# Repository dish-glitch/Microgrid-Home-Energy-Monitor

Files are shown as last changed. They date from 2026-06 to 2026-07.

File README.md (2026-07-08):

# Home Energy Monitor

**A custom PCB that measures real-time household power consumption (Watts, apparent power (VA), and power factor) and streams live data to an OLED screen, a WiFi dashboard, and a Modbus TCP/IP server (the same protocol real industrial power meters use).**







---

## Schematic Preview



---

## PCB Preview



## Enclosure Preview

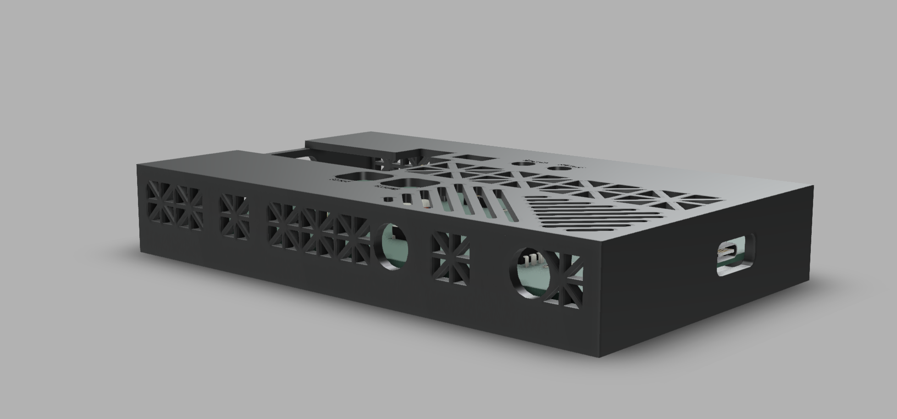
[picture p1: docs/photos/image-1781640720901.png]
Enclosure render

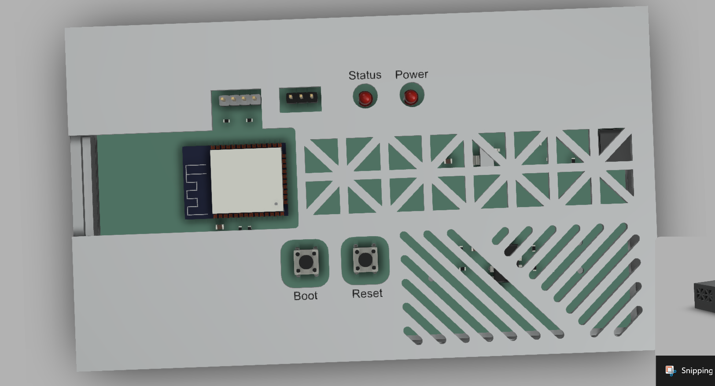
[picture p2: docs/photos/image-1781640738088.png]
Enclosure top view


---

## What It Does

Non-invasive current transformer (CT) sensors clip around household wires inside a breaker box(does not touch any live wires). The custom PCB conditions the signal from the sensors and feeds it to an ESP32 microcontroller. The microcontroller then samples the voltage and current to compute:

- **Real Power (Watts)** 
- **Apparent Power (VA)**
- **Power Factor** 
- **Cumulative kWh** 

The readings come out three ways: a small OLED on the device, a live dashboard served over WiFi that you can open in any browser, and a Modbus TCP/IP server so industrial software like PLCs, SCADA, or Home Assistant can read the meter directly.

---

## How It Works

The SCT-013 current clamp outputs a small AC signal that mirrors the current in the wire it's clamped around. Before the ESP-32 is able to sample the signal, it must condition it. 

1. **It swings negative** — the ESP32 ADC only reads 0–3.3V. An op-amp bias circuit lifts the signal to a 1.65V midpoint so it never goes below 0V.
2. **It's in the wrong units** — a burden resistor converts current to a readable voltage via Ohm's Law (V = I × R).
3. **It carries noise** — an RC low-pass filter passes 60Hz but blocks high-frequency interference.

The ESP32 samples the signal and calculates RMS values in firmware and then uses those measurements to produce real power, apparent power, and power factor. 

---

## Modbus TCP/IP

I added a Modbus TCP server so this works more like a real industrial power meter instead of just a hobby project. Modbus is the protocol that commercial meters from companies like Schneider Electric and ABB use to send their readings to building systems and SCADA software. I got the idea from a PLC Dojo certification I finished on programming Modbus TCP clients and servers, and I wanted to actually use what I learned on my own hardware.

The ESP32 runs the Modbus server on port 502 at the same time as the web dashboard on port 80, so both run off the same WiFi. Any Modbus client, like a PLC, SCADA software, Home Assistant, Node-RED, or even a Python script, can read the meter by asking for its holding registers with Function Code 3.

Modbus registers can only hold 16-bit whole numbers, so I scale the decimal readings into whole numbers before writing them, and the client divides by the same number to get the real value back.

| Register | Modbus Address | Value | Scaling | Example |
|---|---|---|---|---|
| 0 | 40001 | Voltage (Vrms) | ×10 | `1200` → 120.0 V |
| 1 | 40002 | Current CH1 (Irms) | ×100 | `500` → 5.00 A |
| 2 | 40003 | Real Power CH1 (W) | ×1 | `600` → 600 W |
| 3 | 40004 | Apparent Power CH1 (VA) | ×1 | `650` → 650 VA |
| 4 | 40005 | Power Factor | ×100 | `92` → 0.92 |
| 5 | 40006 | Total Energy (kWh) | ×10 | `123` → 12.3 kWh |
| 6 | 40007 | Current CH2 (Irms) | ×100 | `300` → 3.00 A |
| 7 | 40008 | Real Power CH2 (W) | ×1 | `360` → 360 W |

> Register 0 in the code shows up as 40001 in most Modbus software. The 4xxxx numbering is just the standard way holding registers get labeled.

---

## Hardware

> Prices are what you actually pay per order, not per component. Amazon prices fluctuate — check links for current pricing. Order DigiKey items together to share one shipping fee (~$8 flat).

| Component | Ref | Need | What to Buy | Pack | Est. Order Price | Where |
|---|---|---|---|---|---|---|
| ESP32-WROOM-32 module | U1 | 1 | ESP-WROOM-32D 5-pack | 5 | ~$16 | [Amazon][(https://www.amazon.com/ESP-WROOM-32D-ESP-32-Bluetooth-Module-ESP32-WROOM-32D/dp/B085BNHPW5)](https://www.amazon.com/DORHEA-ESP-WROOM-32D-Bluetooth-integrates-ESP32-D0WD/dp/B08XXH9RMT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) |
| CT sensor SCT-013-000 (100A) | J1, J2 sensors | 2 | KOOBOOK 2-pack | 2 | ~$15 | [Amazon](https://www.amazon.com/KOOBOOK-SCT-013-000-Non-invasive-Current-Transformer/dp/B07S4G2Y27) |
| ZMPT101B voltage sensor module | J6 sensor | 1 | Single module | 1 | ~$8 | Amazon |
| Op-amp MCP6002 DIP-8 | U2 | 1 | Juried Engineering 1-pack | 1 | ~$4 | [Amazon](https://www.amazon.com/MICROCHIP-MCP6002-I-MCP6002-Operational-Amplifier/dp/B07GMWJ523) |
| Voltage regulator AMS1117-3.3 | U3 | 1 | 10-pack SOT-223 | 10 | ~$6 | [Amazon](https://www.amazon.com/AMS1117-3-3-LM1117-SOT-223-Voltage-Regulator/dp/B00Y5EKAU2) |
| SMD resistors 0603 (33Ω, 10kΩ, 4.7kΩ, 5.1kΩ, 150Ω) | R1–R14 | 14 total | 0603 assortment kit — covers all 5 values | 660pc / 33 values | ~$9 | [Amazon](https://www.amazon.com/660pcs-0603-Resistors-Assortment-Values/dp/B0CH2XD7JY) |
| SMD capacitors 0603+0805 (100nF, 10µF) | C1–C9 | 9 total | 0603/0805 assortment kit (10pF–22µF) | 960pc / 16 values | ~$10 | [Amazon](https://www.amazon.com/Capacitor-10pF-22uF-Multilayer-Capacitors-Assortment/dp/B094Z9V5KK) |
| 3.5mm audio jack SMT (CUI SJ-3523-SMT) | J1, J2 | 2 | Order 2 individually | 2 | ~$5 | [DigiKey](https://www.digikey.com/en/products/detail/same-sky-formerly-cui-devices/SJ-3523-SMT-TR/281297) |
| USB-C receptacle (GCT USB4085-GF-A) | J4 | 1 | Order 1 individually | 1 | ~$1 | [DigiKey](https://www.digikey.com/en/products/detail/gct/USB4085-GF-A/9859662) |
| 3mm LED (red or green) | D1, D2 | 2 | 10-pack | 10 | ~$5 | [Amazon](https://www.amazon.com/3mm-Round-Top-Red-LED/dp/B017TR4XWW) |
| Tactile button 6×6×4.3mm THT | SW1, SW2 | 2 | 10-pack | 10 | ~$5 | [Amazon](https://www.amazon.com/6x6x4-3mm-Momentary-Tactile-Button-Through/dp/B00EDJYK46) |
| 2.54mm male pin headers (J3 4-pin, J5 6-pin, J6 3-pin) | J3, J5, J6 | 13 pins | 40-pin breakable strip (snap to length) | 10×40 strips | ~$6 | [Amazon](https://www.amazon.com/MCIGICM-Header-2-45mm-Arduino-Connector/dp/B07PKKY8BX) |
| SSD1306 OLED 0.96" I2C | J3 display | 1 | Single unit | 1 | ~$7 | [Amazon](https://www.amazon.com/SSD1306-Display-128x64-Driver-Screen/dp/B0GRGLP6WW) |
| CP2102 USB-to-UART programmer (to flash via J5) | — | 1 | HiLetgo CP2102 | 1 | ~$7 | [Amazon](https://www.amazon.com/HiLetgo-CP2102-Converter-Adapter-Downloader/dp/B00LODGRV8) |
| PCB fabrication | — | 1 run | JLCPCB 5 boards + shipping | 5 boards | ~$20 | [JLCPCB](https://jlcpcb.com) |
| Enclosure | — | 1 | 3D printed PETG-CF | — | $0 | filament on hand |
| DigiKey shipping | — | — | Flat rate (order SJ-3523 + USB4085 together) | — | ~$8 | — |
| **Total** | | | | | **~$132** | |

---

## Repository Structure

```
home-energy-monitor/
├── hardware/        # KiCad schematic, PCB layout, Gerber files
├── firmware/        # ESP32 Arduino code
├── enclosure/       # FreeCAD source + STL files for 3D printing
└── docs/
    └── photos/      # Build progress photos
```

---

## Build Log

| Date | Milestone |
|---|---|
| June 10, 2026 | Project started. Repository initialized. |
| June 11, 2026 | KiCad schematic started — analog front-end both CT channels complete |
| June 13, 2026 | KiCad schematic complete — ERC passes clean, all components wired |
| June 14, 2026 | PCB layout complete — all components placed, routed, ground plane poured, DRC clean |
| June 14, 2026 | Gerbers exported and committed — ready for JLCPCB upload |
| June 14, 2026 | Firmware written — RMS sampling, power math, OLED display, kWh accumulator. Verified on Wokwi simulator. |
| June 15, 2026 | WiFi dashboard complete — ESP32 serves live readings over HTTP, JavaScript polls every second |
| June 16, 2026 | 3D enclosure designed by [@hummos430](https://github.com/hummos430) in Fusion 360 — files committed |
| June 16, 2026 | Stardance funding submitted — S tier $150 |
| July 3, 2026 | DRC audit fixes — solid B.Cu ground plane added, ESP32 thermal via drills fixed, USB-C clearance rule corrected. ERC + DRC verified 0 errors. Gerbers re-exported — board ready to order |
| July 8, 2026 | Modbus TCP/IP server added — ESP32 exposes 8 holding registers on port 502, runs alongside the web dashboard |
| — | PCBs ordered from JLCPCB |
| — | PCBs arrived, soldering complete |
| — | Firmware calibrated, first real power readings |
| — | Dashboard live, full system working |

---

## Simulation

Test the firmware logic without hardware — runs in browser:



Simulates dual CT sensor readings, RMS power math, serial output, and OLED display on a virtual ESP32. CH1 uses test values (120V, 5A, 550W, PF 0.92) to verify the signal chain and kWh accumulator logic.

---

## Status

- [x] KiCad schematic — ERC clean (0 errors)
- [x] PCB layout — DRC clean (0 violations, 0 unconnected); B.Cu ground plane added
- [x] Gerbers exported from the DRC-clean board — ready for JLCPCB upload
- [x] Firmware — ADC sampling + RMS math
- [x] Firmware — power factor calculation
- [ ] PCB fabrication (JLCPCB)
- [x] 3D enclosure design
- [x] WiFi dashboard
- [x] Modbus TCP/IP server (8 holding registers, Function Code 3)
- [ ] Full system test

---

## Acknowledgements

- **[@hummos430](https://github.com/hummos430)** — Designed and 3D printed the enclosure in Fusion 360
- **[Claude (Anthropic)](https://claude.ai)** — Claude was used to help document this project. I often recorded voice notes describing my engineering ideas, design decisions, and progress, then used Claude to organize those notes into structured GitHub documentation and tables. It also helped review the BOM and sanity-check component selections for consistency. The schematic, PCB layout, firmware, testing, and engineering decisions are my own.

---

## License

MIT — use, modify, share freely. See [LICENSE](LICENSE).

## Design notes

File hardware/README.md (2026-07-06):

# Hardware

Custom 2-layer PCB designed in KiCad 9. Measures real-time household power consumption using non-invasive current transformer sensors.

---

## PCB Specifications

| Spec | Value |
|---|---|
| Layers | 2 (F.Cu / B.Cu) |
| Board dimensions | ~130mm × 75mm |
| Min trace width | 0.2mm signal / 0.4mm power |
| Min clearance | 0.15mm (accommodates the USB-C footprint's pad spacing; JLCPCB handles down to 0.127mm) |
| Copper pour | GND flood on F.Cu + solid GND plane on B.Cu, joined by stitching vias |
| Via drill | 0.3mm min |
| Surface finish | HASL (lead-free) |
| Fabrication | JLCPCB |

---

## Design Overview

### Power Path
USB-C (5V VBUS) → AMS1117-3.3 linear regulator → 3.3V rail → ESP32 + all peripherals

CC1 and CC2 resistors (5.1kΩ to GND) identify the board as a USB device to the host charger, enabling 5V/500mA delivery per USB-C spec.

### CT Sensor Signal Conditioning (per channel)
Each channel processes the AC output of an SCT-013-000 current transformer:

```
SCT-013 → 33Ω burden resistor → 10µF coupling cap → MCP6002 op-amp buffer → ESP32 ADC
                                    ↑
                          10kΩ/10kΩ bias divider (1.65V midpoint)
```

1. **Burden resistor (33Ω):** The SCT-013 outputs a small currecnt but the ESP32 measures the voltage. The 33 ohm burden resisotr converts that currecnt into a voltage using Ohm's law. At the senors's max rated current, this produeces 1.65 V RMS 2.33 V peak. 

2. **Bias divider (2× 10kΩ):** Becuase the ESP32 ADC can't read negative voltages, 2 10k ohm resistors create a 1.65 V bais point.
3. **Coupling capacitor (10µF):** Blocks DC from the burden resistor, and passes the 60Hz AC signal.
4. **MCP6002 buffer:** Unity-gain op-amp buffer to keep the bais network independent from the ESP32 ADC. Its high imput impedance prevents the bais voltage from shifting. 

### Voltage Sensing
ZMPT101B voltage transformer connects to J6. its output is routed to GPIO36 which is an input-only ADC pin with no internal pull resistors, chosen to minimize noise on the analog signal.

### I2C Bus
SDA (GPIO21) and SCL (GPIO22) pulled up to 3.3V via 4.7kΩ resistors. Pull-up value chosen for standard-mode I2C (100 kHz) with expected bus capacitance under 50pF.

### ESP32 Boot Circuit
- EN pulled high via 10kΩ (R7) + 100nF to GND for clean power-on reset
- GPIO0 pulled high via 10kΩ (R10); SW2 pulls GPIO0 low for bootloader entry
- SW1 pulls EN low for hard reset

---

## Schematic

See [`Microgrid-Home-Energy-Monitor.kicad_sch`](Microgrid-Home-Energy-Monitor.kicad_sch)

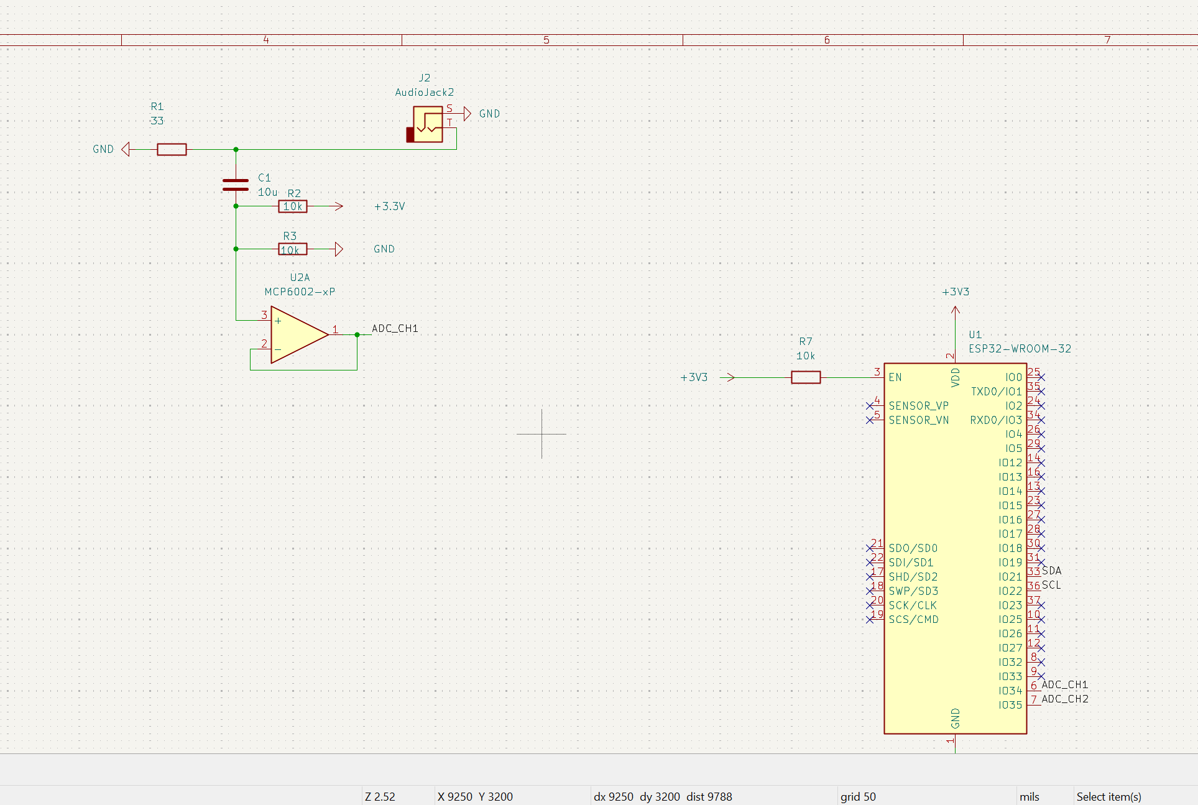
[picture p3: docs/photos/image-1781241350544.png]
Schematic


---

## PCB Layout

See [`Microgrid-Home-Energy-Monitor.kicad_pcb`](Microgrid-Home-Energy-Monitor.kicad_pcb)

Key layout decisions:
- Analog front-end (J1, J2, U2, bias resistors) grouped bottom-right, away from ESP32 WiFi antenna
- ESP32 antenna overhangs the keepout zone — no copper pour under antenna area
- AMS1117 decoupling caps (C3–C6) placed within 2mm of regulator pins
- ESP32 VDD decoupling (C7, C8) placed directly below VDD pin
- USB-C connector (J4) edge-mounted on right wall for direct cable access
- Ground pour floods entire F.Cu layer

---

## Bill of Materials

| Ref | Component | Value | Package | MPN | Supplier |
|---|---|---|---|---|---|
| U1 | ESP32-WROOM-32 | — | Module | ESP32-WROOM-32E-N4 | Mouser 356-ESP32WROOM32EN4 |
| U2 | MCP6002 Op-Amp | — | DIP-8 | MCP6002-I/P | Digikey MCP6002-I/P-ND |
| U3 | AMS1117-3.3 | 3.3V LDO | SOT-223 | AMS1117-3.3 | Digikey 1665-1016-1-ND |
| J1, J2 | CT Sensor Input | 3.5mm jack | SMD | SJ-3523-SMT | Digikey CP-3523SJCT-ND |
| J3 | OLED Connector | 4-pin | 2.54mm header | — | generic |
| J4 | USB-C Receptacle | USB 2.0 | SMD 16P | GCT USB4085-GF-A | Digikey 2073-USB4085-GF-ACT-ND |
| J5 | Programming Header | 6-pin | 2.54mm header | — | generic |
| J6 | ZMPT101B Connector | 3-pin | 2.54mm header | — | generic |
| R1, R2 | Burden Resistor | 33Ω 1% | 0603 | — | generic |
| R3–R6 | Bias Resistor | 10kΩ | 0603 | — | generic |
| R7 | EN Pull-up | 10kΩ | 0603 | — | generic |
| R8, R9 | I2C Pull-up | 4.7kΩ | 0603 | — | generic |
| R10 | GPIO0 Pull-up | 10kΩ | 0603 | — | generic |
| R11, R12 | CC Pull-down | 5.1kΩ | 0603 | — | generic |
| R13, R14 | LED Current Limit | 150Ω | 0603 | — | generic |
| C1, C2 | Coupling Cap | 10µF | 0805 | — | generic |
| C3, C6 | LDO Bulk Cap | 10µF | 0805 | — | generic |
| C4, C5 | LDO Bypass Cap | 100nF | 0603 | — | generic |
| C7 | ESP32 Bypass | 100nF | 0603 | — | generic |
| C8 | ESP32 Bulk | 10µF | 0805 | — | generic |
| C9 | EN Filter Cap | 100nF | 0603 | — | generic |
| D1 | Power LED | Red | 5mm THT | — | generic |
| D2 | Status LED | Green | 5mm THT | — | generic |
| SW1 | Reset Button | — | 6mm THT | — | generic |
| SW2 | Boot Button | — | 6mm THT | — | generic |
| CT1, CT2 | CT Sensor | SCT-013-000 | Clamp | SCT-013-000 | Amazon/AliExpress |
| VT1 | Voltage Sensor Module (plugs into J6) | ZMPT101B | Module | ZMPT101B | Amazon/AliExpress |

---

## Design Verification

All fixes from the 2026-07-02 DRC audit are complete (verified with `kicad-cli`):

- **ERC: 0 errors.** **DRC: 0 violations, 0 unconnected items.**
- GND split-pour islands eliminated by adding a solid B.Cu ground plane with stitching
  vias — front pour fragments all tie to it, so pinch-offs can't strand a ground pin
- ESP32 thermal vias enlarged to 0.3mm drill (JLCPCB 2-layer minimum)
- Minimum clearance set to 0.15mm to fit the USB-C footprint's actual pad spacing

---

## Fabrication Files

Gerber files for JLCPCB are in [`gerbers/`](gerbers/) — exported from the DRC-clean board, **ready to upload**.

JLCPCB order settings:
- Layers: 2
- Dimensions: per gerber
- PCB Qty: 5
- PCB Color: Black
- Surface Finish: HASL(lead-free)
- Copper Weight: 1oz
- All other settings: default

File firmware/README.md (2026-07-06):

# Firmware

The firmware is written in C++ using the Arduino framework and runs on the ESP32. It samples two CT current sensors and a ZMPT101B voltage sensor to calculate real power, apparent power, power factor, and cumulative energy usage. Live measurements are displayed on an SSD1306 and are also available through a built-in WiFi dashboard.

> **Status:** In development — PCB fabrication completing first.

---

## Architecture

```
┌─────────────────────────────────────────────────────┐
│                     ESP32                            │
│                                                      │
│  ADC (GPIO34) ──► CT Channel 1 sampling             │
│  ADC (GPIO35) ──► CT Channel 2 sampling  ──► RMS   ──► Power math
│  ADC (GPIO36) ──► Voltage channel sampling           │
│                                                      │
│  I2C (GPIO21/22) ──► SSD1306 OLED display           │
│  WiFi ──► WebServer ──► Live dashboard               │
└─────────────────────────────────────────────────────┘
```

## Power Calculation

**RMS current** sampled at high frequency over one full 60Hz cycle:

```
I_rms = sqrt( (1/N) * Σ(sample²) )
```

**Real power** (Watts) from instantaneous voltage × current:

```
P = (1/N) * Σ(v[n] * i[n])
```

**Apparent power** (VA):

```
S = V_rms * I_rms
```

**Power factor:**

```
PF = P / S
```

**Cumulative kWh:**

```
kWh += P * (sample_interval_ms / 3600000)
```

---

## Dependencies

| Library | Purpose | Install via |
|---|---|---|
| `EmonLib` | RMS sampling + power math | Arduino Library Manager |
| `Adafruit SSD1306` | OLED driver | Arduino Library Manager |
| `Adafruit GFX` | Graphics primitives | Arduino Library Manager |
| `WiFi` / `WebServer` | WiFi + HTTP dashboard | Built into the ESP32 Arduino core |

---

## Pin Map

| GPIO | Function |
|---|---|
| 34 | ADC CH1 (CT sensor 1) |
| 35 | ADC CH2 (CT sensor 2) |
| 36 (SENSOR_VP) | ADC voltage (ZMPT101B) |
| 21 | I2C SDA (OLED) |
| 22 | I2C SCL (OLED) |
| 2 | Status LED |
| 1 (TX0) | UART TX (programming) |
| 3 (RX0) | UART RX (programming) |

---

## Build & Flash

**Arduino IDE:**
1. Install ESP32 board support: `https://dl.espressif.com/dl/package_esp32_index.json`
2. Select board: `ESP32 Dev Module`
3. Install all dependencies via Library Manager
4. Set upload speed: `921600`
5. **Set `SIMULATION` to `0`** at the top of the sketch — with it at `1` the board
   reports hardcoded Wokwi test values instead of real measurements
6. Set your WiFi SSID/password in the sketch
7. Flash via J5 programming header (FTDI232 or CP2102 USB-serial adapter)

---

## WiFi Dashboard

Once programmed, the ESP32 hosts a web server on port 80. Connect a device to the same WiFi network and open the ESP32's IP address in a web browser. The IP address is printed to the serial monitor during startup.

Dashboard shows:
- Mains voltage (Vrms)
- Channel 1 real power (W) + apparent power (VA)
- Channel 2 apparent power (VA — CH2 has no voltage phase reference, so real W is not available on this channel)
- Power factor (channel 1)
- Cumulative kWh
- Live waveform plot (planned)

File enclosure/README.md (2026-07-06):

# Enclosure

A two-part 3D printed shell designed in Fusion 360 by [@hummos430](https://github.com/hummos430). The enclosure provides access to all external connectors while protecting the PCB. It also includes ventilation around the AMS1117 regulator to improove airflow.

> **Status:** Design complete - files committed. OLED window to be added after screen arrives. PCB mounted with double-sided tape (v1 build; mounting holes planned for PCB v2).

---

## Design

Two-part assembly:
- **Bottom tray** - holds PCB, contains vent pattern below AMS1117, CT jack holes and USB-C cutout on walls
- **Top lid** - LED holes, boot/reset button cutouts, decorative vent pattern

### Dimensions
- **Total height:** 20mm
- **Footprint:** ~136mm × 79mm (130mm × 73mm PCB + 3mm clearance each side)
- **Wall thickness:** 2mm

### External Cutouts

| Feature | Wall | Size |
|---|---|---|
| USB-C port (J4) | Right | 10mm × 4.5mm |
| CT sensor jack 1 (J1) | Front/Bottom | ⌀6.5mm |
| CT sensor jack 2 (J2) | Front/Bottom | ⌀6.5mm |
| OLED 0.96" window (J3) | Top lid | 22mm × 12mm — pending |
| ZMPT101B connector (J6) | Side | Rectangular slot |
| Power LED (D1) | Top lid | ⌀5.2mm |
| Status LED (D2) | Top lid | ⌀5.2mm |
| Reset button (SW1) | Top lid | ⌀4mm recessed |
| Boot button (SW2) | Top lid | ⌀4mm recessed |

The programming header (J5) is located inside the enclosure and is only accessible by removing the lid.

---

## ESP32 Antenna

The ESP32-WROOM-32 antenna is located at the short end of the module opposite the solder pads. Vent slots are included in the wall nearest the antenna. No solid plastic is placed within 5mm of the antenna tip to minimize signal attentuation.

---

## Heat Dissipation

The AMS1117-3.3 regulator typically dissipates around 0.5W at normal load (~300mA). Thermal design:

- **Bottom vent pattern** - decorative cutouts in the floor provide airflow beneath U3
- **Side clearance** - gap between PCB edge and enclosure wall for lateral airflow
- **Open internal cavity** - no foam or insulation inside
- **Material: PETG-CF** - carbon fiber PETG, stiffer and more heat resistant than standard PETG or PLA

---

## Print Settings

| Setting | Value |
|---|---|
| Material | PETG-CF (used) |
| Layer height | 0.2mm |
| Infill | 20% gyroid |
| Perimeters | 3 |
| Supports | No |
| Bed temp | 85°C |
| Nozzle temp | 235°C |

---

## Assembly

- PCB secured with double-sided foam tape (v1)
- 4× M3×8mm screws (lid to tray)

---

## Files

| File | Description |
|---|---|
| `HomecurrentMoniter_BottomPlateHCM updated.f3d` | Fusion 360 source - bottom tray |
| `HomecurrentMoniter_Top Plate HCM UPDATED.f3d` | Fusion 360 source - top lid |
| `HomecurrentMoniter_BottomPlateHCM updated.stl` | Print file - bottom tray |
| `HomecurrentMoniter_Top Plate HCM UPDATED.stl` | Print file - top lid |

**Pictures**



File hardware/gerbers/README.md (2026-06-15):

# Gerbers

Fabrication files for JLCPCB — generated from KiCad 9 after final DRC pass.

> **Status:** Generated June 14, 2026. Ready to upload to JLCPCB.

## Ordering from JLCPCB

1. Zip all files in this folder
2. Upload the zip at [jlcpcb.com](https://jlcpcb.com)
3. Recommended settings:
   - Layers: 2
   - PCB Dimensions: 130mm × 73mm
   - PCB Thickness: 1.6mm
   - Surface Finish: HASL (lead-free)
   - Copper Weight: 1oz
   - Quantity: 5 (minimum, ~$2 base price)

## Files

| File | Description |
|---|---|
| `Microgrid-Home-Energy-Monitor-F_Cu.gtl` | Front copper layer |
| `Microgrid-Home-Energy-Monitor-B_Cu.gbl` | Back copper layer |
| `Microgrid-Home-Energy-Monitor-F_Mask.gts` | Front solder mask |
| `Microgrid-Home-Energy-Monitor-B_Mask.gbs` | Back solder mask |
| `Microgrid-Home-Energy-Monitor-F_Silkscreen.gto` | Front silkscreen |
| `Microgrid-Home-Energy-Monitor-B_Silkscreen.gbo` | Back silkscreen |
| `Microgrid-Home-Energy-Monitor-F_Paste.gtp` | Front solder paste |
| `Microgrid-Home-Energy-Monitor-B_Paste.gbp` | Back solder paste |
| `Microgrid-Home-Energy-Monitor-Edge_Cuts.gm1` | Board outline |
| `Microgrid-Home-Energy-Monitor-PTH.drl` | Plated through-hole drill file |
| `Microgrid-Home-Energy-Monitor-NPTH.drl` | Non-plated through-hole drill file |
| `Microgrid-Home-Energy-Monitor-job.gbrjob` | KiCad Gerber job file |

## How to Regenerate (KiCad 9)

1. Open `Microgrid-Home-Energy-Monitor.kicad_pcb`
2. File → Fabrication Outputs → Gerbers
3. Output folder: `hardware/gerbers/`
4. Layers: F.Cu, B.Cu, F.Paste, B.Paste, F.Silkscreen, B.Silkscreen, F.Mask, B.Mask, Edge.Cuts
5. Check "Use Protel filename extensions"
6. Click Plot, then Generate Drill Files in same dialog

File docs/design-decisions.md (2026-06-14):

# Design Decisions

Engineering decisions made during development and why.

---

## Why SCT-013-000 (100A version)?

The SCT-013-000 is a current output CT (not voltage output). It outputs 0–50mA secondary current for 0–100A primary current. A burden resistor converts this to a voltage the ADC can read.

The 100A range covers typical US residential circuits (most breakers are 15A or 20A per circuit, with a 200A main). The 0–50mA output is easy to condition with a simple passive burden resistor.

**Why not a voltage-output CT?** Voltage-output CTs have internal burden resistors and output ±1V. They require a burden resistor to be removed or bypassed when the clamp is open, and the fixed output range is less flexible. Current-output gives more control over the signal chain.

---

## Why 33Ω burden resistor?

At full scale (100A primary → 50mA secondary):

```
V_peak = I_secondary_peak × R_burden
V_peak = (50mA × √2) × 33Ω = 2.33V peak
```

With the 1.65V bias, the signal swings from ~0V to ~3.3V — exactly filling the ESP32 ADC range without clipping. Any larger and we'd clip; any smaller and we'd waste ADC resolution.

---

## Why MCP6002 op-amp?

Requirements: single-supply 3.3V rail-to-rail input/output, low offset voltage, dual channel (two CT inputs on one chip), DIP package for hand soldering.

MCP6002 meets all of these. It's rated for 1.8V–6V single supply, rail-to-rail I/O, 900µV max offset, dual package (DIP-8). Industry standard for this exact application.

---

## Why SENSOR_VP (GPIO36) for voltage sensing?

GPIO36 (SENSOR_VP) is an input-only ADC pin. It has no internal pull-up or pull-down resistors, making it the lowest-noise ADC input on the ESP32. Voltage measurements are very sensitive to noise, so using the cleanest available pin improves power factor calculation accuracy.

---

## Why AMS1117 instead of a switching regulator?

A buck converter (switching regulator) would be more efficient but introduces switching noise at 100kHz+ that can couple into the analog measurement circuitry. Since the CT sensor signals are at 60Hz, high-frequency noise from a switcher is harder to filter.

The AMS1117 linear regulator dissipates the extra voltage as heat instead of switching. At the current draw of this project (~300mA max), the efficiency loss (~0.5W) is acceptable, and the board stays quiet on the analog side.

---

## Why 4.7kΩ I2C pull-ups?

I2C requires open-drain pull-up resistors. Pull-up value affects:
- Rise time: lower R = faster rise but more current draw
- Range: must keep logic high above 0.7×VCC with capacitive loading

At 3.3V with an SSD1306 OLED (expected bus capacitance ~20pF), 4.7kΩ gives:
```
Rise time τ = R × C = 4700 × 20pF = 94ns
```
Well within the 1000ns maximum for standard-mode I2C (100kHz). 4.7kΩ is the standard recommendation in the I2C spec for 3.3V systems.

---

## Why USB-C instead of micro-USB?

USB-C is the current standard. The GCT USB4085 is a low-cost SMD connector that uses 5.1kΩ resistors on CC1 and CC2 to identify the board as a USB device — any USB-C charger will supply 5V/500mA. No USB 3.x or Power Delivery negotiation needed.

Micro-USB connectors are being phased out and are mechanically weaker (the port is a known failure point on handheld devices). Edge-mounted USB-C is more robust for a wall-mounted energy monitor.

---

## Why no switching on the CT sensor inputs?

CT sensors must never be open-circuited while clamped around a live wire. When the secondary is open, the transformer tries to maintain the turns-ratio voltage — which can be dangerously high. 

The 3.5mm audio jack input keeps the burden resistor always connected across the CT output when a cable is plugged in. When no cable is plugged in (sleeve disconnected), the jack shorts tip-to-sleeve via the switch contact — keeping the CT secondary loaded. This is a known-safe connection method for CT sensors using TRS audio jacks.

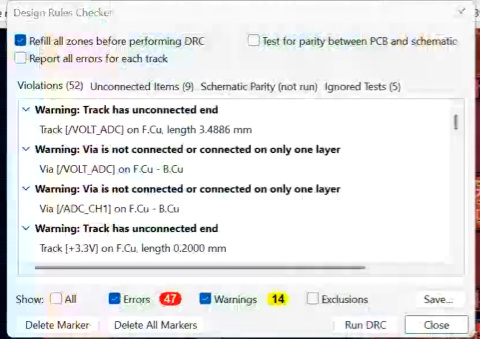
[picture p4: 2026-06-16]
docs/photos/Screenshot 2026-06-16 151825.png

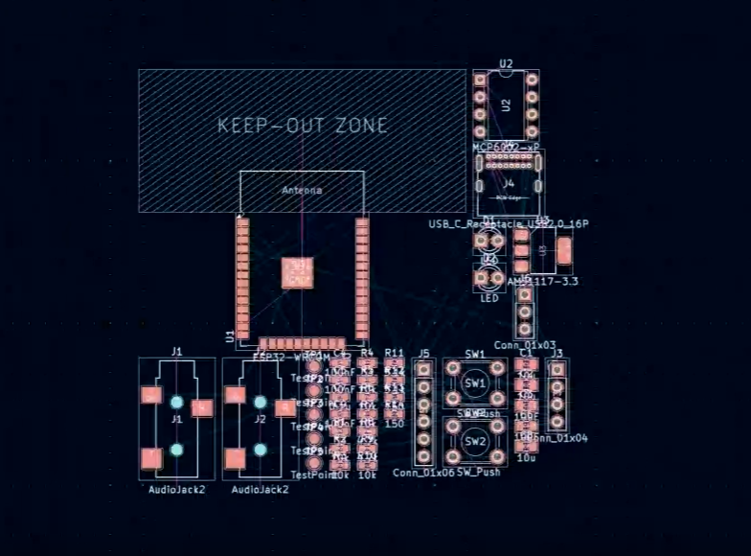
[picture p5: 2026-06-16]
docs/photos/Screenshot 2026-06-16 151732.png

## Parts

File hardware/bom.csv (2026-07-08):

Reference | Component | Value | Package | MPN | Qty | Est Unit Cost (USD) | Supplier
U1 | ESP32-WROOM-32 |  | Module | ESP32-WROOM-32E-N4 | 1 | $4.00 | Mouser
U2 | MCP6002 Op-Amp |  | DIP-8 | MCP6002-I/P | 1 | $0.50 | Digikey
U3 | AMS1117-3.3 | 3.3V LDO | SOT-223 | AMS1117-3.3 | 1 | $0.35 | Digikey
J1 | CT Sensor Jack | 3.5mm stereo | SMD | SJ-3523-SMT | 1 | $0.60 | Digikey
J2 | CT Sensor Jack | 3.5mm stereo | SMD | SJ-3523-SMT | 1 | $0.60 | Digikey
J3 | OLED Connector | 4-pin 2.54mm | THT header |  | 1 | $0.10 | generic
J4 | USB-C Receptacle | USB 2.0 16P | SMD | GCT USB4085-GF-A | 1 | $0.85 | Digikey
J5 | Programming Header | 6-pin 2.54mm | THT header |  | 1 | $0.10 | generic
J6 | ZMPT101B Connector | 3-pin 2.54mm | THT header |  | 1 | $0.10 | generic
R1 | Burden Resistor | 33Ω 1% | 0603 |  | 1 | $0.05 | generic
R2 | Burden Resistor | 33Ω 1% | 0603 |  | 1 | $0.05 | generic
R3 | Bias Resistor | 10kΩ | 0603 |  | 1 | $0.02 | generic
R4 | Bias Resistor | 10kΩ | 0603 |  | 1 | $0.02 | generic
R5 | Bias Resistor | 10kΩ | 0603 |  | 1 | $0.02 | generic
R6 | Bias Resistor | 10kΩ | 0603 |  | 1 | $0.02 | generic
R7 | EN Pull-up | 10kΩ | 0603 |  | 1 | $0.02 | generic
R8 | I2C Pull-up SDA | 4.7kΩ | 0603 |  | 1 | $0.02 | generic
R9 | I2C Pull-up SCL | 4.7kΩ | 0603 |  | 1 | $0.02 | generic
R10 | GPIO0 Pull-up | 10kΩ | 0603 |  | 1 | $0.02 | generic
R11 | CC1 Pull-down | 5.1kΩ | 0603 |  | 1 | $0.02 | generic
R12 | CC2 Pull-down | 5.1kΩ | 0603 |  | 1 | $0.02 | generic
R13 | LED Resistor D1 | 150Ω | 0603 |  | 1 | $0.02 | generic
R14 | LED Resistor D2 | 150Ω | 0603 |  | 1 | $0.02 | generic
C1 | Coupling Cap CH1 | 10µF | 0805 |  | 1 | $0.10 | generic
C2 | Coupling Cap CH2 | 10µF | 0805 |  | 1 | $0.10 | generic
C3 | LDO Input Bulk | 10µF | 0805 |  | 1 | $0.10 | generic
C4 | LDO Output Bypass | 100nF | 0603 |  | 1 | $0.05 | generic
C5 | LDO Input Bypass | 100nF | 0603 |  | 1 | $0.05 | generic
C6 | LDO Output Bulk | 10µF | 0805 |  | 1 | $0.10 | generic
C7 | ESP32 VDD Bypass | 100nF | 0603 |  | 1 | $0.05 | generic
C8 | ESP32 VDD Bulk | 10µF | 0805 |  | 1 | $0.10 | generic
C9 | EN Filter Cap | 100nF | 0603 |  | 1 | $0.05 | generic
D1 | Power LED | Red 3mm | THT |  | 1 | $0.10 | generic
D2 | Status LED | Green 3mm | THT |  | 1 | $0.10 | generic
SW1 | Reset Button | 6mm | THT |  | 1 | $0.15 | generic
SW2 | Boot Button | 6mm | THT |  | 1 | $0.15 | generic
CT1 | CT Sensor | SCT-013-000 100A | Clamp | SCT-013-000 | 1 | $7.00 | Amazon
CT2 | CT Sensor | SCT-013-000 100A | Clamp | SCT-013-000 | 1 | $7.00 | Amazon
VT1 | Voltage Sensor Module (plugs into J6) | ZMPT101B | Module | ZMPT101B | 1 | $8.00 | Amazon
 |  |  |  | PCB Fabrication (JLCPCB 5x) |  |  | $20.00 | JLCPCB
 |  |  |  | TOTAL |  |  | ~$50.00

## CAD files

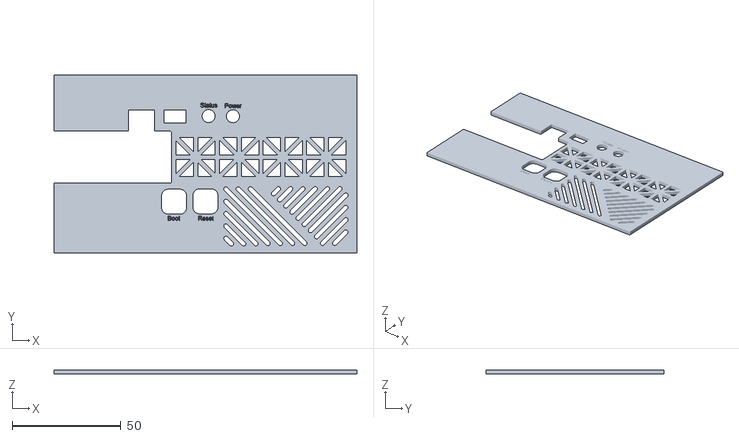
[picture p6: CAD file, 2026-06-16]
enclosure/HomecurrentMoniter_Top Plate HCM UPDATED.stl
139.2 x 81.9 x 2.00

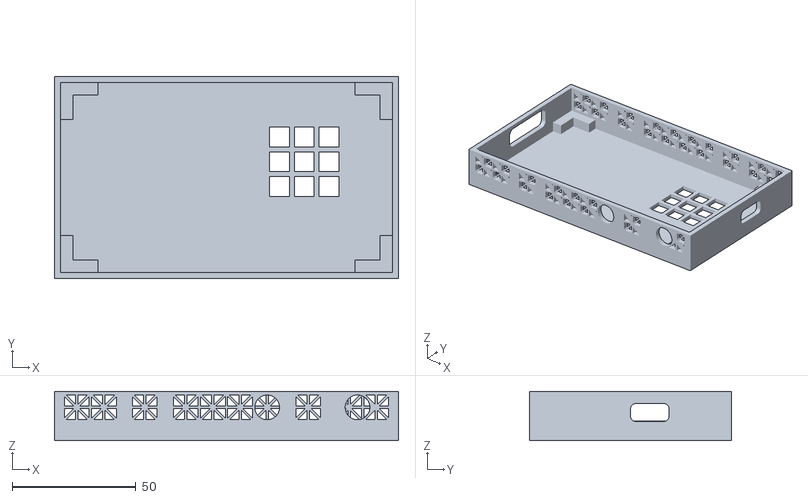
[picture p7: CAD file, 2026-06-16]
enclosure/HomecurrentMoniter_BottomPlateHCM updated.stl
139.2 x 81.9 x 20.0

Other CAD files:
enclosure/HomecurrentMoniter_BottomPlateHCM updated.f3d
enclosure/HomecurrentMoniter_Top Plate HCM UPDATED.f3d

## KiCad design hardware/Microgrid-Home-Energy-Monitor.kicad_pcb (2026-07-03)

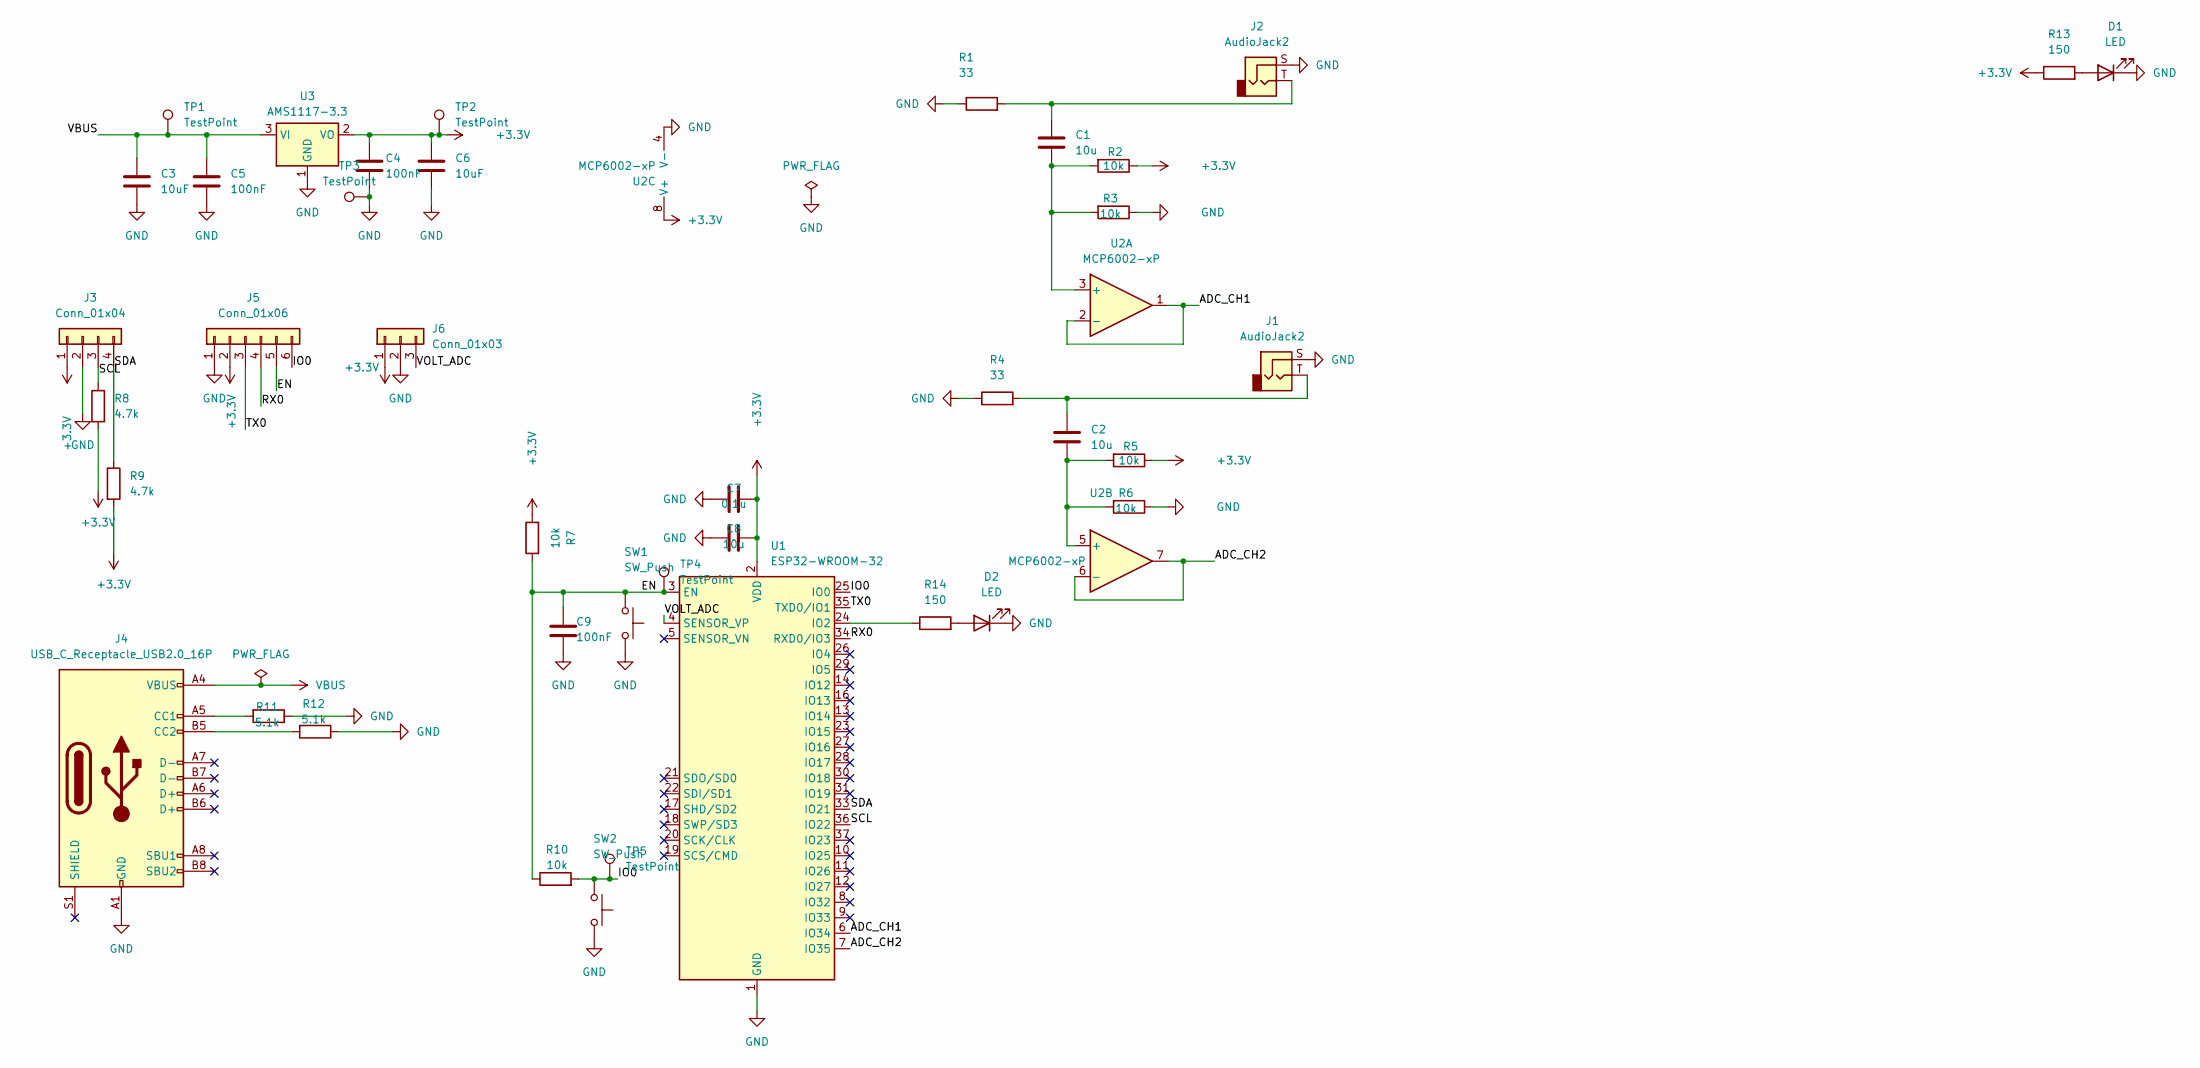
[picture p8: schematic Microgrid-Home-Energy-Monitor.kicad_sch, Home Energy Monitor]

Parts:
C1, C2, C8: 10u; C_0805_2012Metric
C3, C6: 10uF; C_0805_2012Metric
C4, C5, C9: 100nF; C_0603_1608Metric
C7: 0.1u; C_0603_1608Metric
D1, D2: LED; LED_D3.0mm
J1, J2: AudioJack2; Jack_3.5mm_CUI_SJ-3523-SMT_Horizontal
J3: Conn_01x04; PinHeader_1x04_P2.54mm_Vertical
J4: USB_C_Receptacle_USB2.0_16P; USB_C_Receptacle_GCT_USB4085
J5: Conn_01x06; PinHeader_1x06_P2.54mm_Vertical
J6: Conn_01x03; PinHeader_1x03_P2.54mm_Vertical
R1, R4: 33; R_0603_1608Metric
R2, R3, R5, R6, R7, R10: 10k; R_0603_1608Metric
R8, R9: 4.7k; R_0603_1608Metric
R11, R12: 5.1k; R_0603_1608Metric
R13, R14: 150; R_0603_1608Metric
SW1, SW2: SW_Push; SW_PUSH_6mm_H4.3mm
TP1, TP2, TP3, TP4, TP5: TestPoint; TestPoint_Pad_D1.5mm
U1: ESP32-WROOM-32
U2: MCP6002-xP; DIP-8_W7.62mm
U3: AMS1117-3.3; SOT-223-3_TabPin2

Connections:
+3.3V: C4.1, C6.1, C7.2, C8.2, J3.1, J5.2, J6.1, R2.1, R5.1, R7.2, R8.2, R9.2, R13.1, TP2.1, U1.2 (VDD), U2.8 (V+), U3.2 (VO)
/ADC_CH1: U1.6 (IO34), U2.1, U2.2 (-)
/ADC_CH2: U1.7 (IO35), U2.6 (-), U2.7
/EN: C9.1, J5.5, R7.1, R10.1, SW1.1, TP4.1, U1.3 (EN)
/IO0: J5.6, R10.2, SW2.1, TP5.1, U1.25 (IO0)
/RX0: J5.4, U1.34 (RXD0/IO3)
/SCL: J3.3, R8.1, U1.36 (IO22)
/SDA: J3.4, R9.1, U1.33 (IO21)
/TX0: J5.3, U1.35 (TXD0/IO1)
/VOLT_ADC: J6.3, U1.4 (SENSOR_VP)
GND: C3.2, C4.2, C5.2, C6.2, C7.1, C8.1, C9.2, D1.1 (K), D2.1 (K), J1.S, J2.S, J3.2, J4.A1 (GND), J4.A12 (GND), J4.B1 (GND), J4.B12 (GND), J5.1, J6.2, R1.1, R3.1, R4.1, R6.1, R11.1, R12.1, SW1.2, SW2.2, TP3.1, U1.1 (GND), U1.15 (GND), U1.38 (GND), U1.39 (GND), U2.4 (V-), U3.1 (GND)
unnamed: C1.1, J2.T, R1.2
unnamed: C2.1, J1.T, R4.2
unnamed: D1.2 (A), R13.2
unnamed: D2.2 (A), R14.2
unnamed: J4.A5 (CC1), R11.2
unnamed: J4.B5 (CC2), R12.2
unnamed: R14.1, U1.24 (IO2)
unnamed: C1.2, R2.2, R3.2, U2.3 (+)
unnamed: C2.2, R5.2, R6.2, U2.5 (+)
VBUS: C3.1, C5.1, J4.A4 (VBUS), J4.A9 (VBUS), J4.B4 (VBUS), J4.B9 (VBUS), TP1.1, U3.3 (VI)

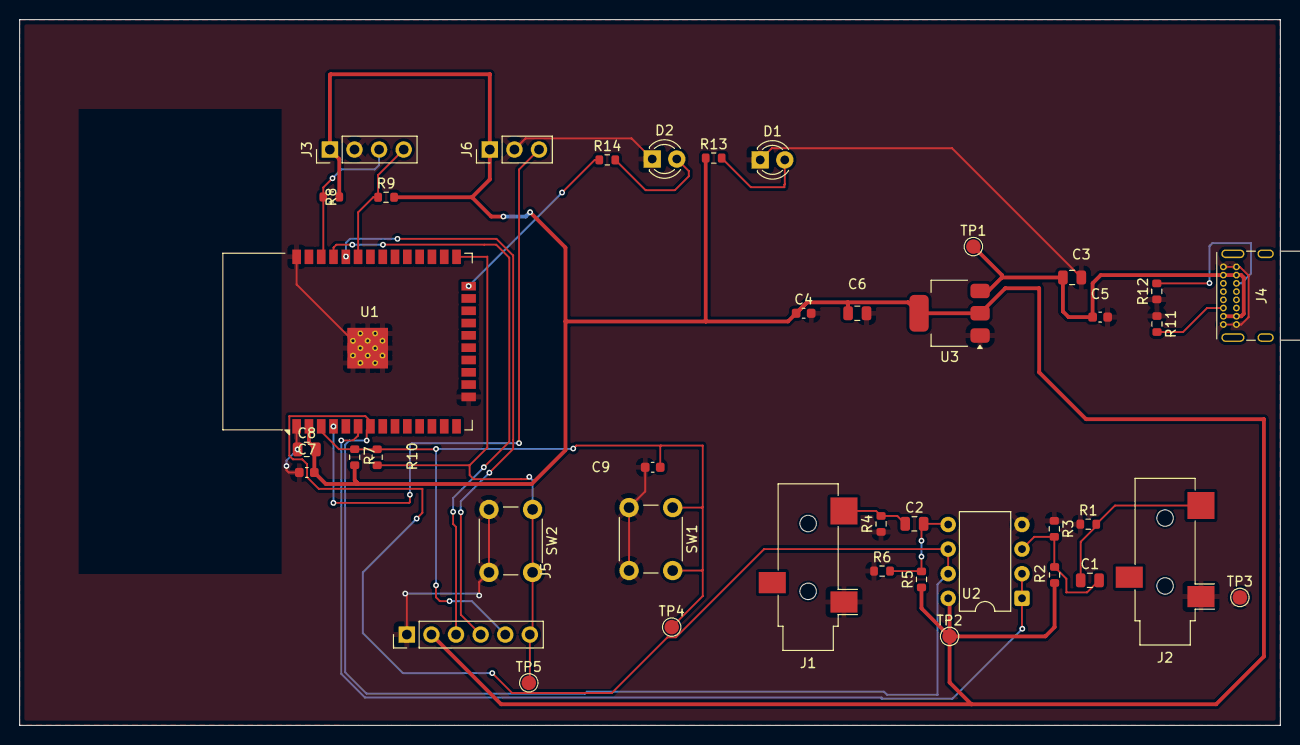
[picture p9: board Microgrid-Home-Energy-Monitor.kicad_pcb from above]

Board: 2 copper layers, 130.2 x 72.9 mm, 41 parts (0 on the bottom side), 21 nets.

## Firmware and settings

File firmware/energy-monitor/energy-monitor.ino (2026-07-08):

#include "EmonLib.h"
#include <Wire.h>
#include <Adafruit_GFX.h>
#include <Adafruit_SSD1306.h>
#include <WiFi.h>
#include <WebServer.h>
#include <ModbusIP_ESP8266.h> // Modbus TCP server


// ================================================
// --- Define ---
// ================================================
#define PIN_CT1 34
#define PIN_CT2 35
#define PIN_VOLTAGE 36
#define PIN_LED 2

#define ICAL 60.6 // fine tune this when the board arrives ((turns ratio(100A)/burdan(0.05))/33(resistor) = 60.6)
#define VCAL 234.26 // fine tune this when you measure with your multimeter.
#define PHASE_SHIFT 1.7 // timing difference

#define SIMULATION 1 // 1 = Wokwi/fake readings, 0 = real board. SET TO 0 BEFORE FLASHING THE REAL BOARD.

#define OLED_WIDTH 128
#define OLED_HEIGHT 64
#define OLED_ADDER 0x3C

const char* WIFI_SSID = "WIFI NAME";   // change <------------------------------
const char* WIFI_PASS = "WIFI PASSWORD"; // change <----------------------------

WebServer server(80);

// ================================================
// --- Modbus TCP server ---
// ================================================
ModbusIP mb; // creates the server. 

// the HREG_VRMS   0 makes it easier to understand insted of using 16 bit numbers. 
#define HREG_VRMS   0 // Vrms         x10   (1200 = 120.0 V)
#define HREG_IRMS1  1 // Irms CH1     x100  (500  = 5.00 A)
#define HREG_WATTS1 2 // real power   x1    (600  = 600 W)
#define HREG_VA1    3 // apparent pwr x1    (650  = 650 VA)
#define HREG_PF     4 // power factor x100  (92   = 0.92)
#define HREG_KWH    5 // total kWh    x10   (123  = 12.3 kWh)
#define HREG_IRMS2  6 // Irms CH2     x100  (300  = 3.00 A)
#define HREG_WATTS2 7 // power CH2    x1    (360  = 360 W)

Adafruit_SSD1306 display(OLED_WIDTH, OLED_HEIGHT, &Wire, -1);

EnergyMonitor ct1;
EnergyMonitor ct2;

float kwh1 = 0.0; // gets energy over time
float kwh2 = 0.0; // gets energy over time
unsigned long lastMillis = 0; // counts up from 0 (time)
bool wifiConnected = false;


// ================================================
// --- HTML(web browser) ---
// ================================================

String getDataJSON() {
  String json = "{";
  json += "\"vrms\":"   + String(ct1.Vrms, 1)             + ",";
  json += "\"watts1\":" + String(ct1.realPower, 1)        + ",";
  json += "\"va1\":"    + String(ct1.apparentPower, 1)    + ",";
  json += "\"va2\":"    + String(ct1.Vrms * ct2.Irms, 1) + ","; // CH2 has no voltage phase ref -> VA, not W
  json += "\"pf\":"     + String(ct1.powerFactor, 2)      + ",";
  json += "\"kwh\":"    + String(kwh1 + kwh2, 4);
  json += "}";
  return json;
}

String getDashboardHTML() {
  String html = R"rawhtml(
<!DOCTYPE html>
<html>
<head>
  <title>Energy Monitor</title>
  <meta name="viewport" content="width=device-width, initial-scale=1">
  <style>
    body { font-family: sans-serif; background: #111; color: #eee; text-align: center; padding: 20px; }
    h1 { color: #4fc3f7; }
    .card { background: #1e1e1e; border-radius: 12px; padding: 20px; margin: 10px auto; max-width: 400px; }
    .value { font-size: 2em; font-weight: bold; color: #4fc3f7; }
    .label { font-size: 0.9em; color: #aaa; margin-top: 4px; }
  </style>
</head>
<body>
  <h1>Home Energy Monitor</h1>
  <div class="card"><div class="value" id="vrms">--</div><div class="label">Voltage (V)</div></div>
  <div class="card"><div class="value" id="watts1">--</div><div class="label">Channel 1 Real Power (W)</div></div>
  <div class="card"><div class="value" id="va1">--</div><div class="label">Channel 1 Apparent Power (VA)</div></div>
  <div class="card"><div class="value" id="va2">--</div><div class="label">Channel 2 Apparent Power (VA)</div></div>
  <div class="card"><div class="value" id="pf">--</div><div class="label">Power Factor</div></div>
  <div class="card"><div class="value" id="kwh">--</div><div class="label">Total (kWh)</div></div>
  <script>
    setInterval(() => {
      fetch('/data')
        .then(r => r.json())
        .then(d => {
          document.getElementById('vrms').innerText   = d.vrms   + ' V';
          document.getElementById('watts1').innerText = d.watts1 + ' W';
          document.getElementById('va1').innerText    = d.va1    + ' VA';
          document.getElementById('va2').innerText    = d.va2    + ' VA';
          document.getElementById('pf').innerText     = d.pf;
          document.getElementById('kwh').innerText    = d.kwh    + ' kWh';
        });
    }, 1000);
  </script>
</body>
</html>
)rawhtml";
  return html;
}


// ================================================
// --- set up ---
// ================================================
void setup() {
  Serial.begin(115200);
  pinMode(PIN_LED, OUTPUT);
  digitalWrite(PIN_LED, HIGH);

  ct1.voltage(PIN_VOLTAGE, VCAL, PHASE_SHIFT);
  ct1.current(PIN_CT1, ICAL);
  ct2.current(PIN_CT2, ICAL);

  Wire.begin(21, 22);
  if (!display.begin(SSD1306_SWITCHCAPVCC, OLED_ADDER)) {
    Serial.println("SSD1306 not found");
    while (true) {
      digitalWrite(PIN_LED, !digitalRead(PIN_LED));
      delay(200);
    }
  }

  display.clearDisplay();
  display.setTextSize(1);
  display.setTextColor(SSD1306_WHITE);
  display.setCursor(0, 0);
  display.println("Energy Monitor");
  display.println("Booting up X_X");
  display.display();
  delay(1000);

// ================================================
// --- Wifi/server set up ---
// ================================================
  WiFi.begin(WIFI_SSID, WIFI_PASS);
  Serial.print("Connecting to WiFi");

  // Try for 10 seconds, then continue without WiFi
  unsigned long wifiStart = millis();
  while (WiFi.status() != WL_CONNECTED && millis() - wifiStart < 10000) {
    delay(500);
    Serial.print(".");
  }

  if (WiFi.status() == WL_CONNECTED) {
    wifiConnected = true;
    Serial.println();
    Serial.print("Connected! IP: ");
    Serial.println(WiFi.localIP());

    server.on("/", [](){
      server.send(200, "text/html", getDashboardHTML());
    });
    server.on("/data", [](){
      server.send(200, "application/json", getDataJSON());
    });
    server.begin();

    // --- Modbus TCP server ---
    mb.server();               // start listening for Modbus clients on port 502
    mb.addHreg(HREG_VRMS);     // create each holding register 
    mb.addHreg(HREG_IRMS1);
    mb.addHreg(HREG_WATTS1);
    mb.addHreg(HREG_VA1);
    mb.addHreg(HREG_PF);
    mb.addHreg(HREG_KWH);
    mb.addHreg(HREG_IRMS2);
    mb.addHreg(HREG_WATTS2);
    Serial.println("Modbus TCP server started on port 502");
  } else {
    Serial.println();
    Serial.println("WiFi not found — running without dashboard");
  }

// ================================================
// --- Time  ---
// ================================================
  lastMillis = millis();
  Serial.println("Set up finished :D");
}


// ================================================
// --- Loop  ---
// ================================================
void loop() {
  ct1.calcVI(20, 2000);
  ct2.calcIrms(1480);

#if SIMULATION
  // Fake readings so the Wokwi sim shows realistic numbers.
  // Compiled out entirely when SIMULATION is 0.
  ct1.Vrms         = 120.0;
  ct1.Irms         = 5.0;
  ct1.realPower    = 550.0;
  ct1.apparentPower = 600.0;
  ct1.powerFactor  = 0.92;
  ct2.Irms         = 3.0;
#endif

  float Vrms        = ct1.Vrms;
  float Irms1       = ct1.Irms;
  float Irms2       = ct2.Irms;
  float watts1      = ct1.realPower;
  float val1        = ct1.apparentPower;
  float powerFactor1 = ct1.powerFactor;
  float watts2      = Vrms * Irms2;

  unsigned long now = millis();
  float fullHours = (now - lastMillis) / 3600000.0;
  kwh1 += (watts1 / 1000.0) * fullHours;
  kwh2 += (watts2 / 1000.0) * fullHours;
  lastMillis = now;

  // --- Push readings into the Modbus registers ---
  // Multiply by the scale factor then send the number to what the register  an hold.
  mb.Hreg(HREG_VRMS,   (uint16_t)(Vrms         * 10));  // 120.0 V -> 1200 << here is a example. 
  mb.Hreg(HREG_IRMS1,  (uint16_t)(Irms1        * 100)); 
  mb.Hreg(HREG_WATTS1, (uint16_t)(watts1));             
  mb.Hreg(HREG_VA1,    (uint16_t)(val1));               
  mb.Hreg(HREG_PF,     (uint16_t)(powerFactor1 * 100)); 
  mb.Hreg(HREG_KWH,    (uint16_t)((kwh1 + kwh2) * 10)); 
  mb.Hreg(HREG_IRMS2,  (uint16_t)(Irms2        * 100)); 
  mb.Hreg(HREG_WATTS2, (uint16_t)(watts2));             

  Serial.printf("V:%.1fV  CH1:%.2fA %.1fW PF:%.2f  CH2:%.2fA %.1fW  kWh:%.4f\n",
    Vrms, Irms1, watts1, powerFactor1, Irms2, watts2, kwh1 + kwh2);

  display.clearDisplay();
  display.setTextSize(1);
  display.setCursor(0, 0);
  display.printf("Voltage: %.1f V", Vrms);
  display.setCursor(0, 16);
  display.printf("CH1: %.1f W  PF %.2f", watts1, powerFactor1);
  display.setCursor(0, 28);
  display.printf("CH2: %.1f W", watts2);
  display.setCursor(0, 44);
  display.printf("Total: %.3f kWh", kwh1 + kwh2);
  display.display();

  if (wifiConnected) {
    server.handleClient(); // answer web browsers (port 80)
    mb.task();             // answer Modbus clients  (port 502)
  }

  delay(500);
}

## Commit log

2026-06-12 add KiCad schematic — analog front-end both CT channels
    [Microgrid-Home-Energy-Monitor.kicad_pcb, Microgrid-Home-Energy-Monitor.kicad_sch]
2026-06-12 update README — fix burden resistor value, add build log entry
2026-06-12 add OLED connector, USB-C power input, AMS1117 regulator, decoupling caps
    [Microgrid-Home-Energy-Monitor.kicad_sch]
2026-06-12 complete schematic — ERC clean, all components wired
    [Microgrid-Home-Energy-Monitor.kicad_sch]
2026-06-12 complete schematic, add schematic screenshots to README
2026-06-13 Complete schematic fixes: USB-C, decoupling caps, boot/reset buttons, I2C pullups, programming header, ZMPT101B connector
    [Microgrid-Home-Energy-Monitor.kicad_sch]
2026-06-14 Complete PCB layout and routing - DRC clean
    [Microgrid-Home-Energy-Monitor.kicad_pcb]
2026-06-14 Update README — PCB layout complete, fix build log
2026-06-14 Add professional hardware docs, BOM, design decisions, gerber instructions
    [bom.csv]
2026-06-15 Add Gerber fabrication files and update PCB with refilled copper pour
    Gerbers generated from KiCad 9 for JLCPCB 2-layer fabrication.
    Includes F.Cu, B.Cu, paste, mask, silkscreen, Edge.Cuts, and drill files.
    PCB updated with refreshed GND zone fill before export.
    [Microgrid-Home-Energy-Monitor-B_Cu.gbl, Microgrid-Home-Energy-Monitor-B_Mask.gbs, Microgrid-Home-Energy-Monitor-B_Paste.gbp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]
2026-06-15 Update gerbers README — files generated, add JLCPCB ordering instructions
2026-06-15 Add ESP32 firmware — RMS sampling, power math, OLED display
    Reads dual CT sensors (GPIO34/35) and ZMPT101B voltage (GPIO36).
    Calculates real power, apparent power, power factor, and cumulative kWh
    using EmonLib. Displays live readings on SSD1306 OLED and serial monitor.
    Calibration constants (ICAL/VCAL) to be tuned against real meter on arrival.
2026-06-15 Add Wokwi simulation link and update status
    Firmware milestones checked off. Simulation at wokwi.com/projects/466868484916087809
    verified RMS math, serial output, and kWh accumulator logic on virtual ESP32.
2026-06-15 Add WiFi dashboard — live web server with JSON data endpoint
    ESP32 hosts a webpage on port 80 serving live power readings.
    JavaScript polls /data every second and updates cards without page refresh.
    Switched from ESPAsyncWebServer to built-in WebServer.h for ESP32 core compatibility.
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2026-06-15 Add WiFi timeout and test values for simulation
    WiFi connection now times out after 10s instead of blocking forever.
    Board runs without dashboard if WiFi unavailable (useful for testing).
    Test values added in loop() for Wokwi simulation — marked for removal before real board.
2026-06-16 Add 3D enclosure — Fusion 360 source and STL files
    Two-part enclosure designed by friend in Fusion 360.
    Bottom tray with CT jack holes, USB-C cutout, and ventilation pattern.
    Top lid with LED holes, boot/reset button cutouts, and airflow slots.
    OLED window to be added after screen arrives.
    PETG recommended, 130mm x 73mm PCB footprint.
    [HomecurrentMoniter_BottomPlateHCM updated.f3d, HomecurrentMoniter_BottomPlateHCM updated.stl, HomecurrentMoniter_Top Plate HCM UPDATED.f3d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]
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2026-06-16 Add build progress photos — enclosure renders and PCB screenshots
2026-06-16 Audit and update repo — enclosure README, build log, enclosure photos in README
    - Enclosure README updated: correct file names, PETG-CF material, actual cutout sizes, antenna note, hummos430 credit
    - Build log updated: enclosure and Stardance submission entries added
    - Enclosure renders added to main README
2026-06-16 Add Amazon purchase links to hardware BOM, fix enclosure material
2026-06-16 Revamp BOM with actual order prices, pack sizes, and smaller quantities
2026-06-16 Add missing AMS1117-3.3 voltage regulator to BOM
2026-06-16 Complete BOM overhaul from schematic audit
    - Fix resistors/capacitors to SMD 0603/0805 (were wrongly listed as through-hole)
    - Fix audio jacks to CUI SJ-3523-SMT (were wrongly listed as panel-mount through-hole)
    - Fix USB-C to bare GCT USB4085 receptacle on PCB (not a breakout board)
    - Add missing: D1/D2 LEDs, SW1/SW2 buttons, J3/J5/J6 pin headers
    - Add missing 4.7k and 150 ohm resistor values to notes
    - Add CP2102 USB-to-UART programmer (needed to flash via J5)
    - Add schematic reference designators to each row
    - Add DigiKey as source for SJ-3523 and USB4085
    - Update total to ~$124
2026-07-03 Audit fixes: missing ZMPT101B in BOMs, DRC pre-order checklist, doc accuracy
    - BOMs (README table, hardware README, bom.csv): add the ZMPT101B voltage
    sensor module itself -- only its J6 connector was listed. Totals updated
    ($124 -> $132 order cost; $42 -> $50 component cost).
    - hardware/README: add pre-order fix checklist from fresh kicad-cli DRC run
    (GND zone islands on F.Cu, 12 ESP32 thermal vias at 0.2mm drill vs 0.3mm
    min, 19 USB-C pad clearance errors vs 0.2mm netclass); mark committed
    gerbers stale until re-export. ERC verified clean (0 errors).
    - hardware/README: burden resistor math corrected -- 100A gives 1.65V RMS
    (2.33V peak), so the signal clips above ~70A RMS; fine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
    [bom.csv]
2026-07-03 Fix all DRC errors; sync fixed board + fresh Gerbers into repo
    Board fixes (done in KiCad GUI):
    - Added solid GND plane on B.Cu; stitching vias tie front pour fragments
    to it -- eliminates the split-pour GND islands permanently
    - ESP32 thermal vias: 0.2mm -> 0.3mm drill (JLCPCB 2-layer minimum)
    - Min clearance relaxed to fit the USB-C (J4) footprint's 0.15mm pad gaps
    Verified with kicad-cli: DRC 0 violations, 0 unconnected. ERC 0 errors.
    Gerbers + drill files re-exported from the fixed board -- ready for JLCPCB.
    Note: the repo previously carried a stale June 14 copy of the board; the
    edited project lived outside the repo. This commit syncs the real files.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
    [Microgrid-Home-Energy-Monitor-B_Cu.gbl, Microgrid-Home-Energy-Monitor-B_Mask.gbs, Microgrid-Home-Energy-Monitor-B_Paste.gbp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]
2026-07-03 Docs: board verified clean -- replace pre-order checklist with results
    - hardware/README: pre-order fix checklist replaced with verification
    summary (ERC 0, DRC 0); specs updated -- min clearance 0.15mm, GND
    pour now F.Cu flood + solid B.Cu plane with stitching vias; Gerbers
    marked ready to upload
    - README: status checklist all green through Gerber export; build log
    entry for the July 3 DRC fixes
2026-07-08 Add Modbus TCP/IP server alongside web dashboard
    ESP32 now runs a Modbus TCP server on port 502 in parallel with the
    HTTP dashboard on port 80. Exposes 8 holding registers (Vrms, per-channel
    current/power, VA, power factor, kWh) readable by any Modbus client via
    Function Code 3. Float readings scaled to 16-bit integers.
    README documents the register map and dual-protocol interface.
2026-07-08 Add STEP enclosure model and gerbers zip
    STEP file requested by Hack Club reviewer for the enclosure.
    Gerbers bundled as a zip for direct JLCPCB upload.
2026-07-08 Fix LED size in BOM: 5mm -> 3mm to match board footprint
    D1/D2 use the LED_D3.0mm through-hole footprint on the PCB;
    the BOM incorrectly listed 5mm.
    [bom.csv]
2026-07-09 Add Python Modbus TCP client for testing the register interface
    tools/modbus_read.py reads all 8 holding registers over Modbus TCP
    (Function Code 3) and decodes them back to engineering units using the
    firmware's scaling. Pure Python (socket + struct), no dependencies.
    Verified against the firmware running on a real ESP32: registers
    1200/500/92 decode to 120.0V / 5.00A / 0.92 PF as expected.
2026-10-23 Add board bring-up test sketch
    Blinks D2, scans I2C for the OLED, reads the BOOT button and prints
    the CT1/CT2/voltage ADC inputs so a newly assembled board can be
    checked before the sensors are connected.
    Claude-Session: https://claude.ai/code/session_01TaWktt9vX2DpLdon3FwWNB
2026-10-28 Document board bring-up and fix BOM errors found during assembly
    - BOM: burden resistors are R1/R4 (not R1/R2), bias resistors are
    R2/R3/R5/R6; J4 is through-hole and optional; R10 must not be fitted
    on rev 1 (PCB wires it EN-GPIO0); LEDs are 3mm
    - Hardware README: assembly notes (resistor markings, R10, bench power
    via VBUS, U2 orientation, programming without auto-reset, OLED pin
    order) and a bring-up checklist
    - Firmware README: add modbus-esp8266 dependency, current board
    manager URL, WiFi limits, manual BOOT/RESET flashing, board-test usage
    - README: build log, status, and build photos of the working board
    Claude-Session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
2026-10-28 Add more build photos: board top view, OLED, firmware serial output
    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
2026-10-29 Add web dashboard screenshot from the assembled board
    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
2026-10-29 Add Modbus TCP read output from the assembled board
    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
2026-11-02 Set ESP32 ADC to 10-bit so EmonLib scaling is correct
    EmonLib defines ADC_BITS as 10 on non-ARM targets (ESP32 is Xtensa),
    while the ESP32 core reads 12-bit by default. That made every reading
    4x too high, and calcVI() never saw the midpoint start condition
    (45-55% of ADC_COUNTS), so it waited for its full timeout each loop.
    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
2026-11-10 Calibrate ICAL from first real current measurement
    A 300 W rice cooker read 2.40 A on CH1 against 2.50 A expected at
    120 V, so ICAL goes from the theoretical 60.6 to 63.1. Record the
    measurement in the build log, document the calibration procedure, and
    add peak-to-peak readings to board-test for setting the ZMPT101B
    trimmer.
    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
